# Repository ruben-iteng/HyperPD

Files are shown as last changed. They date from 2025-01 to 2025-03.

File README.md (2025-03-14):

<div align="center">

# HyperPD

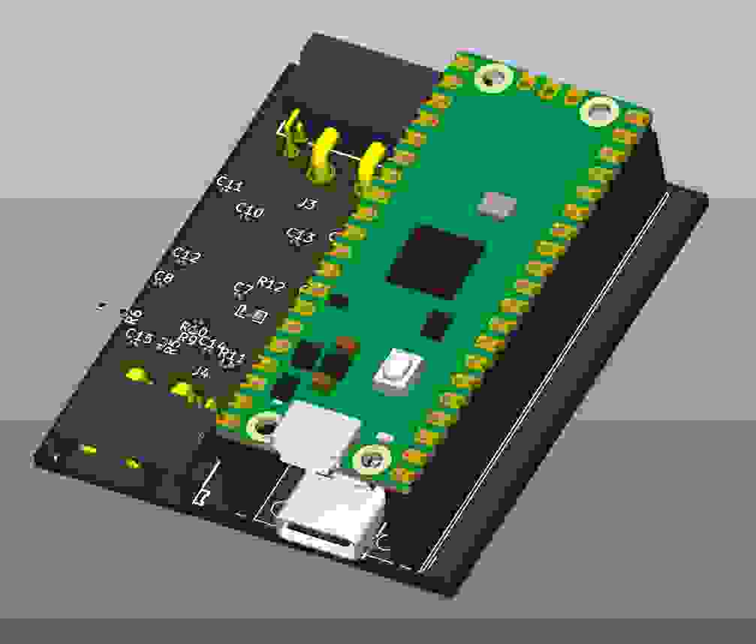
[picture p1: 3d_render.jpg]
Render

<br/>

HyperHDR LED controller with USB-PD power input 

    

</div>

## About

HyperPD is a HyperHDR compatible LED controller with USB-PD as power source. By using XT30 connectors with 2 additional data pins, you can use pre-assembled cables that you only need to solder to your LED strip! All these features make this a very compact and easy to connect solution.

### Features

- USB-C PD power input (15V and 20V)
- 5V @ 8A continuous output for the LEDs
- XT30(2x2) connectors for easy connection to the LED strips
- Support for SPI and WS2812/SK6812 LED strips
- Support for multi-segment LED strip setups
- 100% compatible with HyperSerialPico firmware

## Making your own

Buy the following components:

- Raspberry Pi Pico (or pin compatible board)
- USB-C PD Power Supply
  - This board supports 15V and 20V power input
  - Match the wattage with your LED strip, higher wattage is okay/better
- 1 or 2 [XT30 cables](https://www.aliexpress.com/item/1005007527109751.html)
- The HyperPD board (order the assembled board on JLCPCB or make your own)
- 3D printed case (optional, see [here](./mechanical/README.md))

## Firmware

Firmware informationcan be found [here](./firmware/README.md).

## Mechanical

Files for a 3D printable case can be found [here](./mechanical/README.md).

## Development

Setup atopile:

- Guide can be found [here](https://docs.atopile.io/).

Build the project:

```bash
# In the root of the project
# Using uv to install the dependencies
uv sync
uv run pip install -e .
# Local install is needed for local fabll module imports
```

Build the project default target to generate release artifacts (Gerber, STEP, BOM, P&P,etc.):
```bash
# In the root of the project
atopile build
```

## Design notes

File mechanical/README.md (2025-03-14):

<div align="center">

# Mechanical

Render
<br/>

</div>

A simple 3D printable case is included in this project.

## STL files

- `hyperpd_case_top.3mf` - Top of the case.
- `hyperpd_case_bottom.3mf` - Bottom of the case.
- `hyperpd_vesa_mount_200x300.3mf` - VESA mount adapter.

## Fusion 360 files

- `hyperpd_case.f3d` - Full case design.

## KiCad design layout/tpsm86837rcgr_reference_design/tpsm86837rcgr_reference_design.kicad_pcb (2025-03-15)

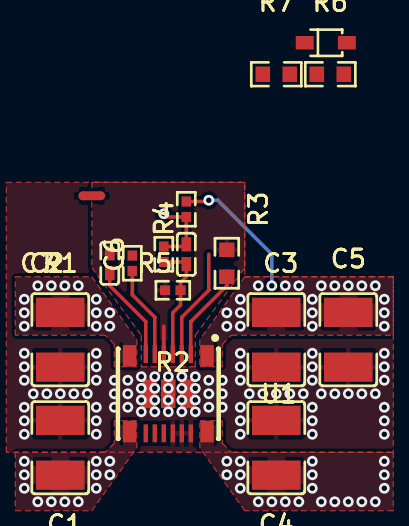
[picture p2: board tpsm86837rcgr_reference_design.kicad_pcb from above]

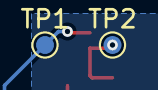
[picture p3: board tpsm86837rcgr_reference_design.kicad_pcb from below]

Board: 2 copper layers, 19 parts (2 on the bottom side), 12 nets.

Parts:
C1, C2: 10µF ±10% 35V X7R; C1210-c93926
C3, C4, C5: 22µF ±10% 25V X7R; C1210-c93926
C6: 47pF ±5% 50V C0G; C0402-b3ef17
C7: 22nF ±10% 50V X7R; C0402-b3ef17
D1: SOD-323_L1.8-W1.3-LS2.5-RD-b55baa
JP1: NetTie-2_SMD_Pad0.5mm
R1: 100kΩ ±1% 62.5mW; R0402-56259e
R2, R4: 10kΩ ±1% 62.5mW; R0402-56259e
R3: 49.9Ω ±1% 62.5mW; R0402-56259e
R5, R7: 10kΩ ±1% 100mW; R0603-ebcab9
R6: 1kΩ ±1% 100mW; R0603-ebcab9
TP1, TP2: TestPoint_Pad_D1.0mm
U1: B3QFN-19_L5.5-W5.0-P0.50-TL-114622

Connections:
frequency_mode: R5.1, U1.2
gnd: C1.2, C2.2, C3.2, C4.2, C5.2, D1.2, JP1.1, R6.2, U1.13, U1.14, U1.15, U1.17, U1.18, U1.19
gnd-1: C7.2, JP1.2, R2.2, R5.2, U1.5
hv: C3.1, C4.1, C5.1, U1.1, U1.16
hv-2: C1.1, C2.1, R7.1, U1.8, U1.9
line: D1.1, R6.1, R7.2, U1.3
line-1: R1.1, U1.6
line-2: C6.1, R2.1, R4.2, U1.4
output_voltage_feedback-contact: C6.2, R3.2, R4.1, TP2.1
output_voltage_feedback-contact-1: R3.1, TP1.1
soft_start: C7.1, U1.7
switching_node: U1.10, U1.11

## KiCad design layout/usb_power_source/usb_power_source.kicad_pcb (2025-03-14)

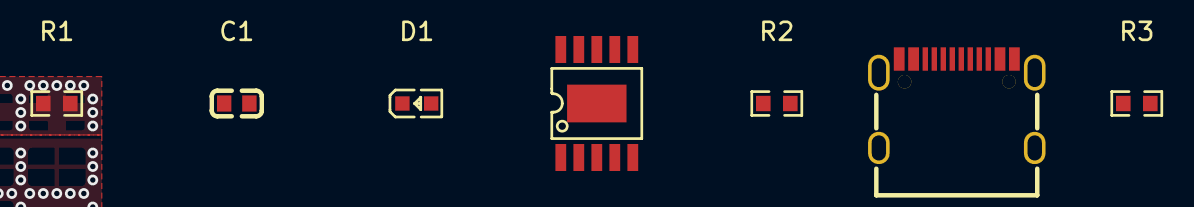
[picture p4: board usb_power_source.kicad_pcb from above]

Board: 2 copper layers, 7 parts (0 on the bottom side), 11 nets.

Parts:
C1: 1µF ±10% 50V X5R; C0603-bd72f6
D1: LED0603-RD-YELLOW-5af84a
J1: USB-C_SMD-TYPE-C-31-M-12-8412ae
R1, R2: 10kΩ ±1% 100mW; R0603-ebcab9
R3: 1kΩ ±1% 100mW; R0603-ebcab9
U1: ESSOP-10_L4.9-W3.9-P1.0-LS6.0-TL-EP-20a8ca

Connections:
cathode: D1.1, R1.1
cc[0]: J1.A5, U1.7
cc[1]: J1.B5, U1.6
gnd: C1.2, J1.A1, J1.A12, J1.B1, J1.B12, U1.11
gnd-1: R1.2, U1.10
hv: D1.2, J1.A4, J1.A9, J1.B4, J1.B9, R2.2, R3.2
line: J1.A6, J1.B6, U1.4
line-1: J1.A7, J1.B7, U1.5
shield: J1.0, J1.1, J1.2, J1.3
usb_pr_trigger-hv: C1.1, R3.1, U1.1
usb_pr_trigger-line: R2.1, U1.8

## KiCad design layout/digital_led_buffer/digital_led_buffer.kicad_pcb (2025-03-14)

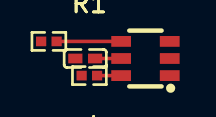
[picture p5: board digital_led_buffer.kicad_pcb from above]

Board: 2 copper layers, 4 parts (0 on the bottom side), 4 nets.

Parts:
C1: 100nF ±10% 16V X7R; C0402-b3ef17
R1, R2: 470Ω ±1% 62.5mW; R0402-56259e
U1: SOT-23-6_L2.9-W1.6-P0.95-LS2.8-BR-bfc73b

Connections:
gnd: C1.2, U1.2
hv: C1.1, U1.5
line-1: R1.2, U1.6
line-2: R2.2, U1.4

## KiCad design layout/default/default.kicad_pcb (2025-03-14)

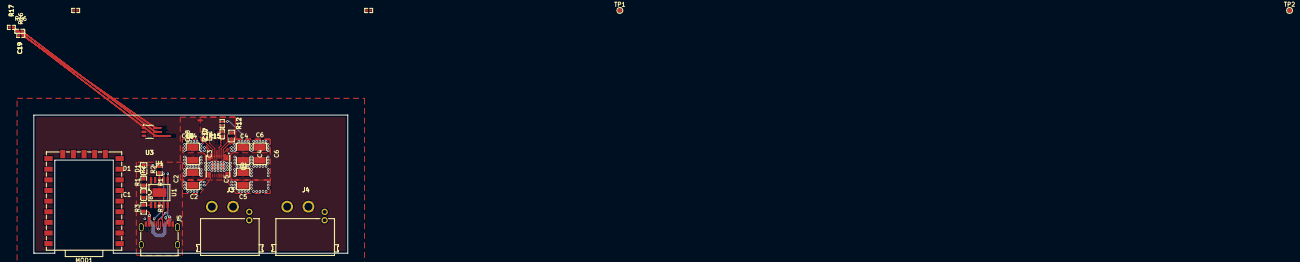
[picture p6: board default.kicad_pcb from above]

Board: 2 copper layers, 30 parts (0 on the bottom side), 25 nets.

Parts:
C1: 1µF ±10% 50V X5R; C0603-bd72f6
C2, C3: 10µF ±10% 35V X7R; C1210-c93926
C4, C5, C6: 22µF ±10% 25V X7R; C1210-c93926
C17: 47pF ±5% 50V C0G; C0402-b3ef17
C18: 22nF ±10% 50V X7R; C0402-b3ef17
C19: 100nF ±10% 16V X7R; C0402-b3ef17
D1: LED0603-RD-YELLOW-5af84a
J3, J4: CONN-TH_4P-XT30PW-M-e6a65c
J5: USB-C_SMD-TYPE-C-31-M-12-8412ae
JP1: NetTie-2_SMD_Pad0.5mm
MOD1: COMM-SMD_RP2040-ZERO-70d39b
R1, R2: 10kΩ ±1% 100mW; R0603-ebcab9
R3: 1kΩ ±1% 100mW; R0603-ebcab9
R4: 100kΩ ±1% 62.5mW; R0402-56259e
R5, R6: 10kΩ ±1% 62.5mW; R0402-56259e
R12: 49.9Ω ±1% 62.5mW; R0402-56259e
R15: 162kΩ ±1% 100mW; R0603-ebcab9
R16, R17: 470Ω ±1% 62.5mW; R0402-56259e
TP1, TP2: TestPoint_Pad_D1.0mm
U1: ESSOP-10_L4.9-W3.9-P1.0-LS6.0-TL-EP-20a8ca
U2: B3QFN-19_L5.5-W5.0-P0.50-TL-114622
U3: SOT-23-6_L2.9-W1.6-P0.95-LS2.8-BR-bfc73b

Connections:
cathode: D1.1, R1.1
cc[0]: J5.A5, U1.7
cc[1]: J5.B5, U1.6
clock: J3.4, J4.4, R17.1
data: J3.3, J4.3, R16.1
dcdc_module-gnd: C18.2, JP1.2, R5.2, R15.2, U2.5
dcdc_module-line: C17.1, R5.1, R6.2, U2.4
dcdc_module-line-2: R4.1, U2.6
dcdc_module.output_voltage_feedback-contact: C17.2, R6.1, R12.2, TP2.1
dcdc_module.output_voltage_feedback-contact-1: R12.1, TP1.1
frequency_mode: R15.1, U2.2
gnd: C1.2, C2.2, C3.2, C4.2, C5.2, C6.2, C19.2, J3.2, J4.2, J5.A1, J5.A12, J5.B1, J5.B12, JP1.1, MOD1.22, U1.11, U2.13, U2.14, U2.15, U2.17, U2.18, U2.19, U3.2
hv-2: C4.1, C5.1, C6.1, C19.1, U2.1, U2.16, U3.5
led_buffer-line: R17.2, U3.4
led_buffer-line-1: R16.2, U3.6
line: MOD1.4, U3.1
line-1: MOD1.3, U3.3
pd_power_supply-gnd: R1.2, U1.10
pd_power_supply-line: J5.A6, J5.B6, U1.4
pd_power_supply-line-1: J5.A7, J5.B7, U1.5
pd_power_supply.usb_pr_trigger-hv: C1.1, R3.1, U1.1
pd_power_supply.usb_pr_trigger-line: R2.1, U1.8
shield: J5.0, J5.1, J5.2, J5.3
soft_start: C18.1, U2.7
vbus: C2.1, C3.1, D1.2, J5.A4, J5.A9, J5.B4, J5.B9, R2.2, R3.2, U2.8, U2.9

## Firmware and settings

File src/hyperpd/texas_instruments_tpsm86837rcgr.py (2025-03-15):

# This file is part of the faebryk project
# SPDX-License-Identifier: MIT

import logging

from atopile.errors import UserNotImplementedError
import faebryk.library._F as F  # noqa: F401
from faebryk.core.module import Module
from faebryk.libs.library import L  # noqa: F401
from faebryk.libs.units import P  # noqa: F401
from faebryk.libs.picker.picker import DescriptiveProperties
from faebryk.libs.util import assert_once

logger = logging.getLogger(__name__)


class TEXAS_INSTRUMENTS_TPSM86837RCGR(Module):
    """
    Power Management Modules 4.5V to 28V input voltage, 8A ECO mode,
    synchronous buck module with QFN package
    """

    # ----------------------------------------
    #               modules
    # ----------------------------------------

    # ----------------------------------------
    #              interfaces
    # ----------------------------------------
    power_out = L.d_field(lambda: F.ElectricPower().make_source())  # pins: 1, 16
    frequency_mode: F.Electrical  # pin: 2
    enable: F.EnablePin  # pin: 3
    feedback: F.ElectricSignal  # pin: 4
    power_analog: F.ElectricPower  # pin: 5
    power_good: F.ElectricLogic  # pin: 6
    soft_start: F.Electrical  # pin: 7
    power_in: F.ElectricPower  # pins: 8, 9
    switching_node: F.Electrical  # pins: 10, 11
    """
    Do not connect, only for better thermal dissipation and reduced parasitic impedance.
    """
    # n.c. bootstrap: F.Electrical  # pin: 12
    # power_ground: F.Electrical  # pins: 17, 18, 19

    # ----------------------------------------
    #               parameters
    # ----------------------------------------
    output_voltage = L.p_field(
        units=P.V,
        likely_constrained=True,
        soft_set=L.Range(0.6 * P.V, 5.5 * P.V),
    )
    switching_frequency = L.p_field(
        units=P.kHz,
        likely_constrained=True,
        soft_set=L.DiscreteSet(800 * P.kHz, 1200 * P.kHz),
    )
    soft_start_time = L.p_field(
        units=P.ms,
        likely_constrained=True,
        soft_set=L.Range(0 * P.ms, 1000 * P.ms),
    )
    # under_voltage_lockout = L.p_field(units=P.V)

    # ----------------------------------------
    #                 traits
    # ----------------------------------------
    designator_prefix = L.f_field(F.has_designator_prefix)(
        F.has_designator_prefix.Prefix.U
    )
    descriptive_properties = L.f_field(F.has_descriptive_properties_defined)(
        {
            DescriptiveProperties.manufacturer: "TEXAS INSTRUMENTS",
            DescriptiveProperties.partno: "TPSM86837RCGR",
        }
    )
    datasheet = L.f_field(F.has_datasheet_defined)(
        "https://www.ti.com/lit/ds/symlink/tpsm86838.pdf"
    )

    @L.rt_field
    def bridge(self):
        return F.can_bridge_defined(self.power_in, self.power_out)

    # TODO: fix, don't connect analog power to ground
    # @L.rt_field
    # def single_electric_reference(self):
    #    return F.has_single_electric_reference_defined(
    #        F.ElectricLogic.connect_all_module_references(self, exclude=self.analog_power,gnd_only=True)
    #    )

    @L.rt_field
    def attach_via_pinmap(self):
        return F.can_attach_to_footprint_via_pinmap(
            {
                "1": self.power_out.hv,
                "2": self.frequency_mode,
                "3": self.enable.enable.line,
                "4": self.feedback.line,
                "5": self.power_analog.lv,
                "6": self.power_good.line,
                "7": self.soft_start,
                "8": self.power_in.hv,
                "9": self.power_in.hv,
                "10": self.switching_node,
                "11": self.switching_node,
                "12": None,  # self.bootstrap,
                "13": self.power_in.lv,
                "14": self.power_in.lv,
                "15": self.power_in.lv,
                "16": self.power_out.hv,
                "17": self.power_in.lv,
                "18": self.power_in.lv,
                "19": self.power_in.lv,
            }
        )

    def __preinit__(self):
        # ------------------------------------
        #           connections
        # ------------------------------------

        # ------------------------------------
        #          parametrization
        # ------------------------------------
        self.power_in.voltage.constrain_subset(L.Range(4.5 * P.V, 28 * P.V))
        self.power_out.voltage.constrain_subset(self.output_voltage)

        # TODO: sofset is currently not used so constrain manually
        self.power_out.voltage.constrain_subset(L.Range(0.6 * P.V, 5.5 * P.V))
        self.switching_frequency.constrain_subset(
            L.DiscreteSet(800 * P.kHz, 1200 * P.kHz)
        )
        self.soft_start_time.constrain_subset(L.Range(0 * P.ms, 1000 * P.ms))

        # The datasheet does not specify a specific voltage, but there is an image of
        # the internal circuitry showing a 5V rail
        # self.power_analog.voltage.constrain_subset(
        #    L.Range.from_center_rel(5 * P.V, 10 * P.percent)
        # ) TODO: unsolvable ...

        # The datasheet does not specify a specific current, 60uA is calculated from
        # the recommended component values in the datasheet (Table 7-2)
        self.feedback.reference.max_current.constrain_subset(
            L.Range.from_center_rel(60 * P.uA, 10 * P.percent)
        )

        # TODO: no support for high/low/hysteresis/min/max voltage for ElectricLogic
        # self.enable.has_single_electric_reference.reference.voltage.constrain_subset(
        #    L.Range(0.5 * P.V, 5.5 * P.V)
        # )

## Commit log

2025-01-03 Add pico footprint submodule
2025-01-10 Make v0.3.x compatible
    [default.kicad_pcb, hyperpd.kicad_pcb, main.kicad_pcb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]
2025-01-24 Split into modules, and add first layout
    [default.kicad_pcb, hyperpd.kicad_pcb, tpsm86837rcgr_reference_design.kicad_pcb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]
2025-01-28 Change PCB layout
    [default.kicad_pcb, tpsm86837rcgr_reference_design.kicad_pcb, usb_power_source.kicad_pcb]
2025-02-25 Add LED buffer, change DCDC func to params, layout
    [SN74LVC2G34.kicad_pcb, default.kicad_pcb, digital_led_buffer.kicad_pcb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]
2025-03-08 Add missing LED connector
    Use different buffer
2025-03-08 Add pcb files
    [SN74LVC2G34.kicad_pcb, default.kicad_pcb, digital_led_buffer.kicad_pcb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]
2025-03-14 Restructure project
    Add documentaion
    Fix Reference design
    [SN74LVC2G34.kicad_pcb, default.kicad_pcb, digital_led_buffer.kicad_pcb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]
2025-03-14 Connect SW pins to eachother for better performance
    From: https://e2e.ti.com/support/power-management-group/power-management/f/power-management-forum/1433607/tpsm86838-do-the-sw-pins-need-to-be-connected-to-each-other-tpsm8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
2025-03-15 Make UVLO compile
    [tpsm86837rcgr_reference_design.kicad_pcb]

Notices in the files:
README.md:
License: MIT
